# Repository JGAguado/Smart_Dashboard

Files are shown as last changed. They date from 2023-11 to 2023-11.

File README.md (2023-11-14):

[][documentation]
[][releases]
[](LICENSE)

[][maintenance]
[][buymecoffee]

# Smart Dashboard
The Smart Dashboard is a platform to help display any kind of information on two kinds of ePaper display: the 7.5" black & white display and the 7.3" 7-colors display, both from Waveshare. It includes a BMP280 sensor for air temperature and pressure as well as all the electronics to work with the minimum power consumption, supporting solar charging.

<p float="left">
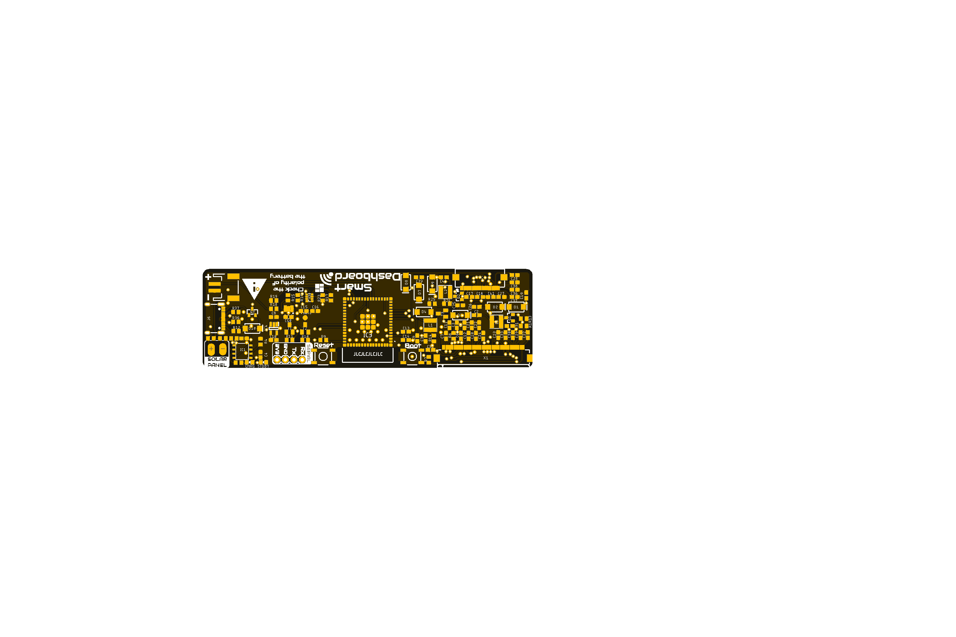
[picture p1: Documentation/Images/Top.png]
   
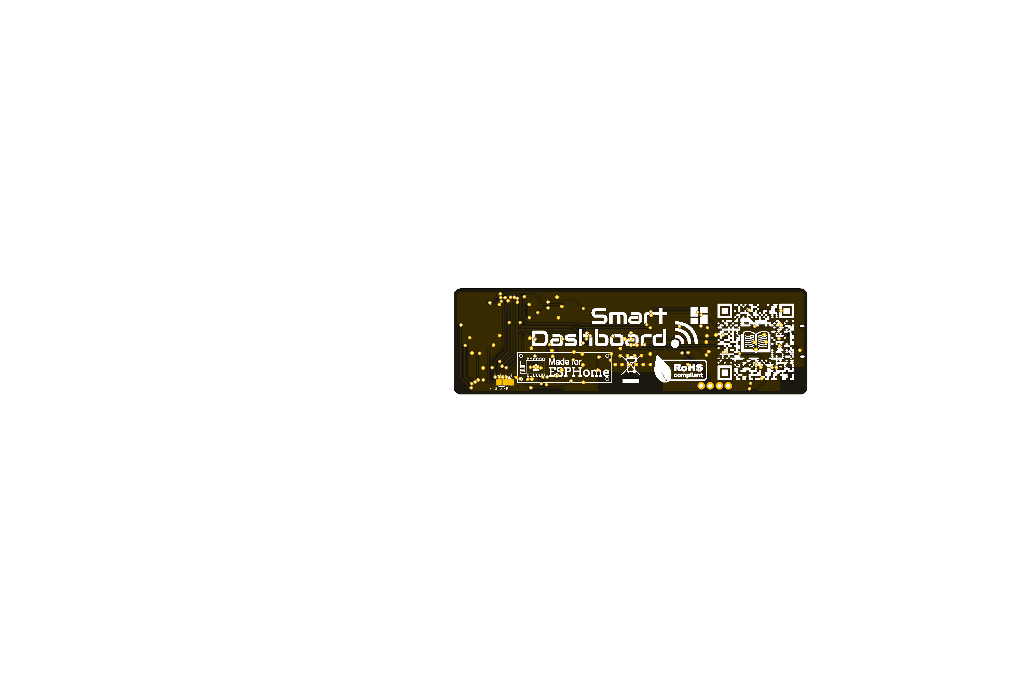
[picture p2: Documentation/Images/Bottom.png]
      
</p>

## Project tree

<li><a href="./Design/">Design</a></li>
<li><a href="./Documentation/">Documentation</a></li>

<li><a href="./README.md">README.md</a></li>

[documentation-shield]: https://readthedocs.org/projects/smart-dashboard/badge/?version=latest&style=for-the-badge
[documentation]: https://smart-dashboard.readthedocs.io

[releases-shield]: https://img.shields.io/github/release/JGAguado/Smart_Dashboard.svg?style=for-the-badge
[releases]: https://github.com/JGAguado/Smart_Dashboard/releases

[license-shield]: https://img.shields.io/badge/License-CC%20BY--NC--SA%204.0-lightgrey.svg?style=for-the-badge

[maintenance-shield]: https://img.shields.io/badge/maintainer-J.%20G.%20Aguado-blue.svg?style=for-the-badge
[maintenance]: https://github.com/JGAguado

[buymecoffee-shield]: https://img.shields.io/badge/buy%20me%20a%20coffee-support-yellow.svg?style=for-the-badge
[buymecoffee]: https://www.buymeacoffee.com/J.G.Aguado

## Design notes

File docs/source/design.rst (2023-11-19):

📐 Design
===========================

Electronic schematics
---------------------
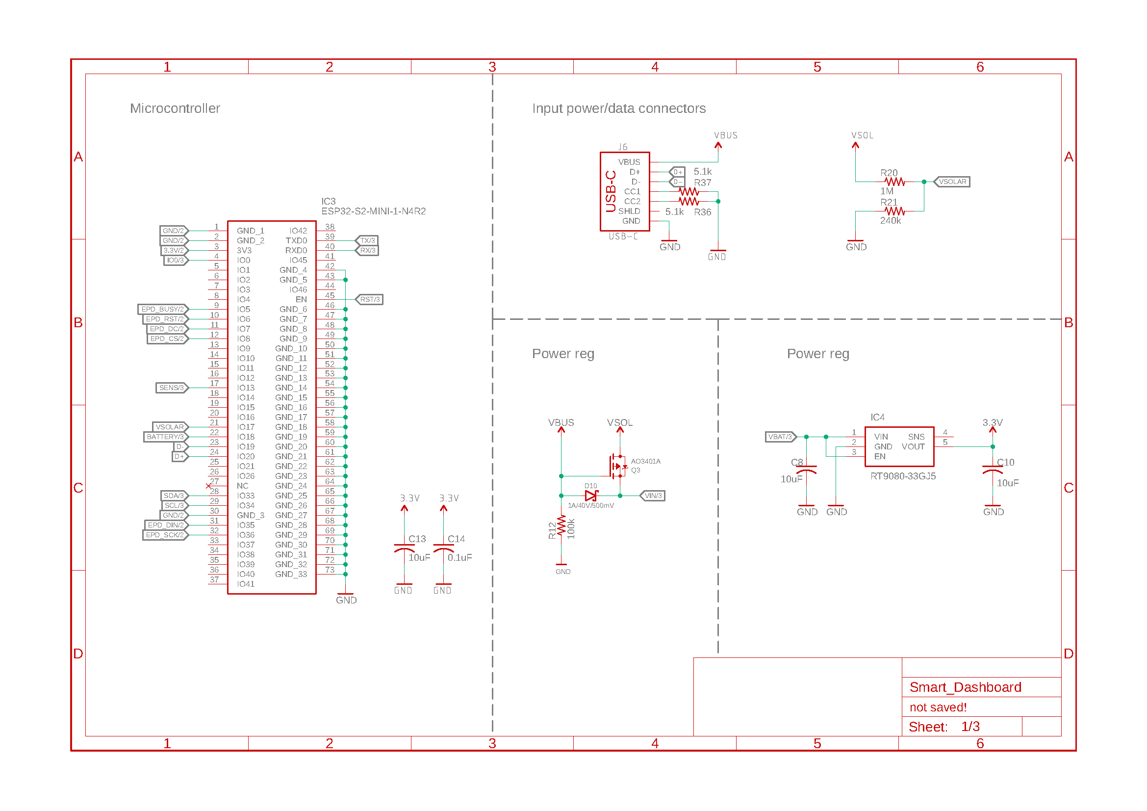
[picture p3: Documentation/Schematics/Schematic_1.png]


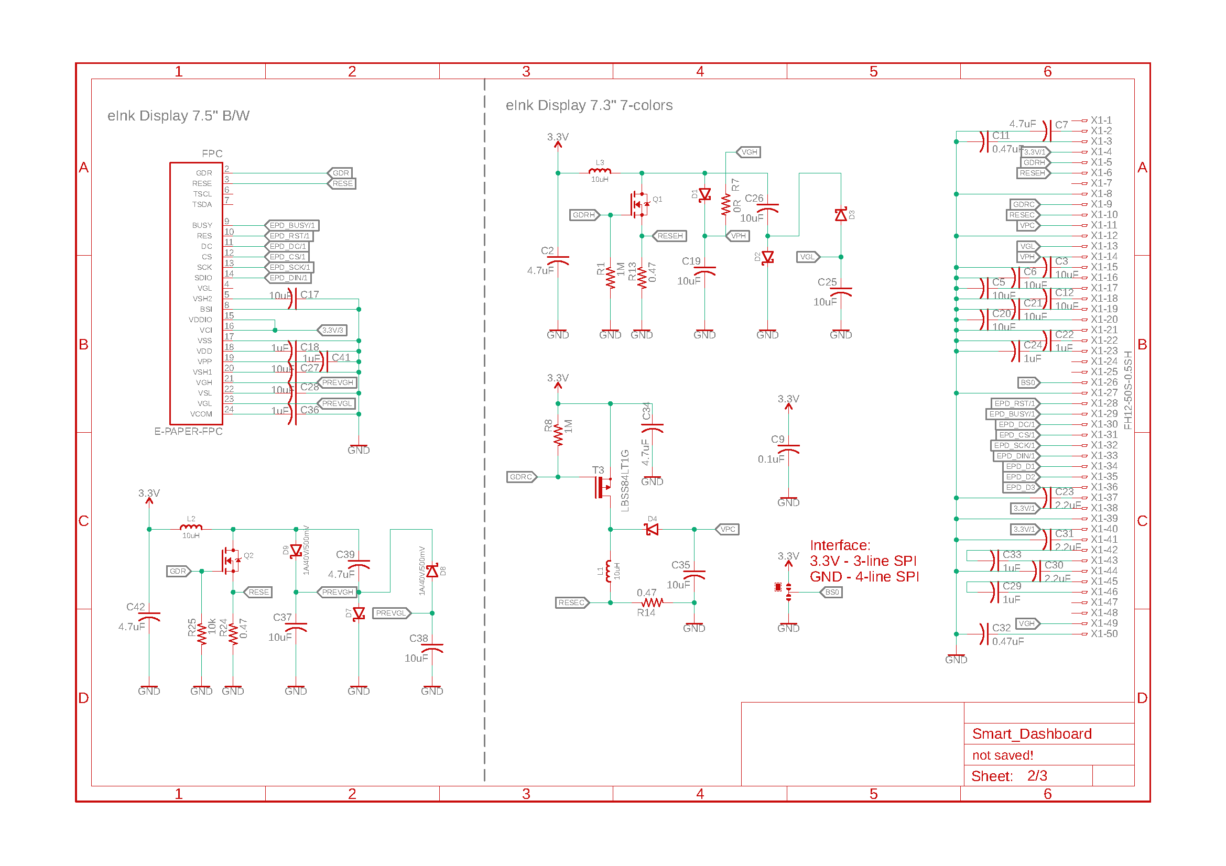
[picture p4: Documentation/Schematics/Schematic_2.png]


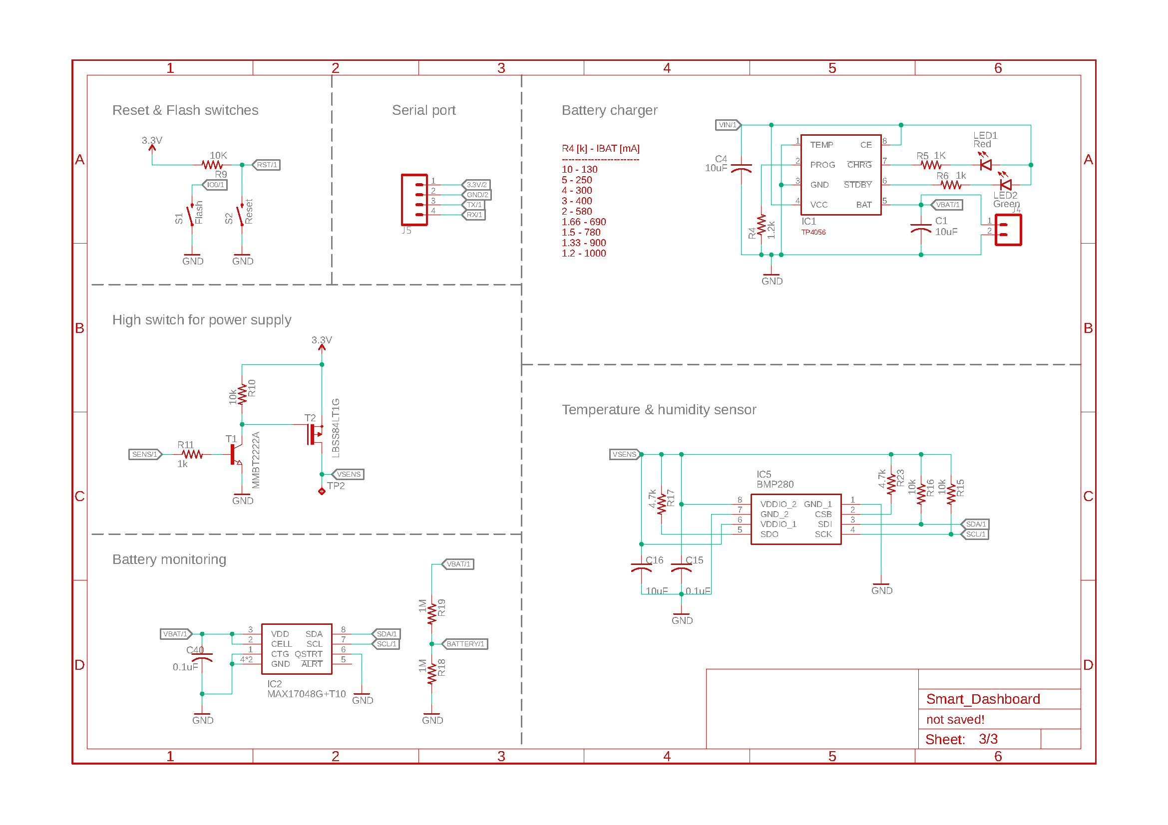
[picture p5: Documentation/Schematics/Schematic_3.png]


:download:`Download PDF <../../Documentation/Schematics/Schematic.pdf>`

.. _pcb:

:term:`PCB`
----------

.. raw:: html

    <iframe src="_static/ibom.html" height="800px" width="100%"></iframe>

.. _dock:

Dock stand
-----------------------

.. Caution::
    The following enclosure was designed for 5050100 (100x50x5mm) 4000mAh LiPo battery. The recommended battery wouldn't fit in this enclosure.

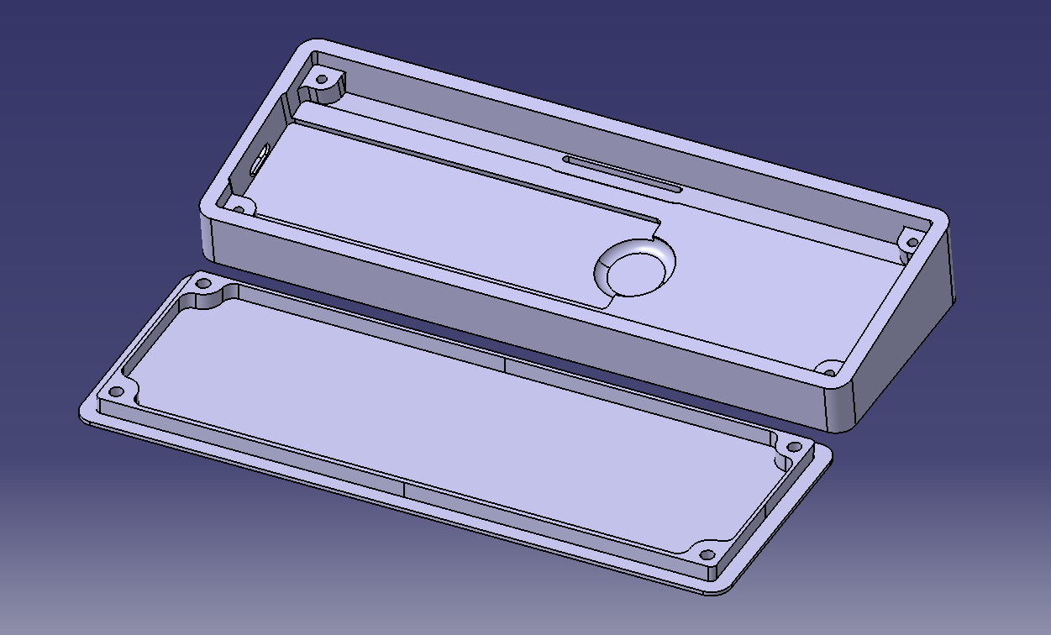
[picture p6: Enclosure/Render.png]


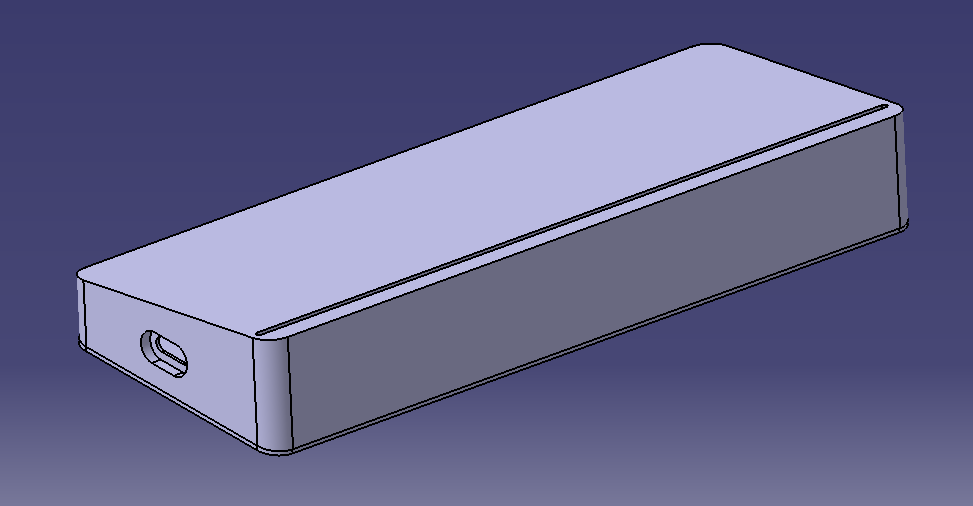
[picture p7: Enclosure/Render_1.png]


|
- :download:`Bottom <../../Enclosure/Bottom.stl>`
- :download:`Top <../../Enclosure/Top.stl>`

Technical Specifications
--------------------------

Microcontroller 
^^^^^^^^^^^^
.. list-table:: 
    :widths: 50 80
    :stub-columns: 1

    * - Module
      - ESP32-S2-MINI-1
    * - SoC
      - Xtensa® singlecore 32-bit LX7 up to 240MHz
    * - Flash
      - 4MB
    * - PSRAM
      - 2MB

Power
^^^^^^^^^^^^

.. list-table:: 
    :widths: 50 80
    :stub-columns: 1

    * - Battery 
      - LiPo 3.7 V 5000 mAh
    * - Input (USB/Solar panel)
      - 5V @ 500mA

Features
^^^^^^^^^^^^

.. list-table:: 
    :widths: 50 80
    :stub-columns: 1

    * - Interface 
      - USB Type C 
    * - 
      - 2.4GHz WiFi 
    * - 
      - UART
    * - Display
      - 7.5" B&W E-Ink display 
    * - 
      - 7.3" ACeP 7-Color E-Ink Display
    * - Sensors
      - BMP280 air temperature & pressure (digital :math:`I^2C`)
    * - 
      - MAX17048 battery voltage level sensor (digital :math:`I^2C`)

Dimensions
^^^^^^^^^^^^

.. list-table:: 
    :widths: 50 80
    :stub-columns: 1

    * - Size 
      - 100x30mm
    * - Weight
      - 15g

Environment
^^^^^^^^^^^^

.. list-table:: 
    :widths: 50 20 20 20 20 20
    :header-rows: 1
    :stub-columns: 1

    * - Parameter
      - Symbol
      - Min.
      - Typ.
      - Max.
      - Unit
    * - Working temperature [1]_
      - :math:`T_{amb}`
      - 0
      - 25 
      - 60
      - *°C*
    * - Storage temperature [1]_
      - :math:`T_{amb}`
      - 0
      - 25 
      - 60
      - *°C*

.. [1] Based on components datasheets.

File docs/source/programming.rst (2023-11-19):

💻 Programming
===============

There are two main programming methods supported and tested with the |Product|: 
 * ESPHome
 * Arduino

In both scenarios, you will first need to enter the board into flashing mode. For that, press and hold the *Flash* pushbutton
while you reset the board (pressing once the *Reset* pushbutton).

.. Note::
    For flashing new firmwares, if the :term:`OTA` support is not available, you can use the USB-C or the serial port (3.3, GND, Tx, Rx).

.. Caution::
    If you decide to flash the board through the serial port, make sure to unplug the battery before (the 3.3V supply is shared).

.. _esphome:
ESPHome
---------
`ESPHome <https://esphome.io>`_ is a well known platform for programming ESP-based devices 
with a very little effort. It is configured via YAML files and supports a wide range of functionalities
and sensors.

.. Note::
    At the moment, ESPHome only supports single-color E-Ink displays, so the 7-color display can **not** be used with ESPHome.

.. Important::
    For using ESPHome, and all its funcionalities, you need to have a `Home Assistant <https://www.home-assistant.io>`_ (HA) instance running
    in the same network as your |Product|.

.. Tip::
    A very easy way to upload and copy files (code or even images) into your ESPHome folder hosted in your HA instance is 
    with the help of the Visual Studio Code integration for HA. This way you can just drag and drop the files over the folder 
    on the Home Assistant’s Visual Studio Code navigation panel on your left.

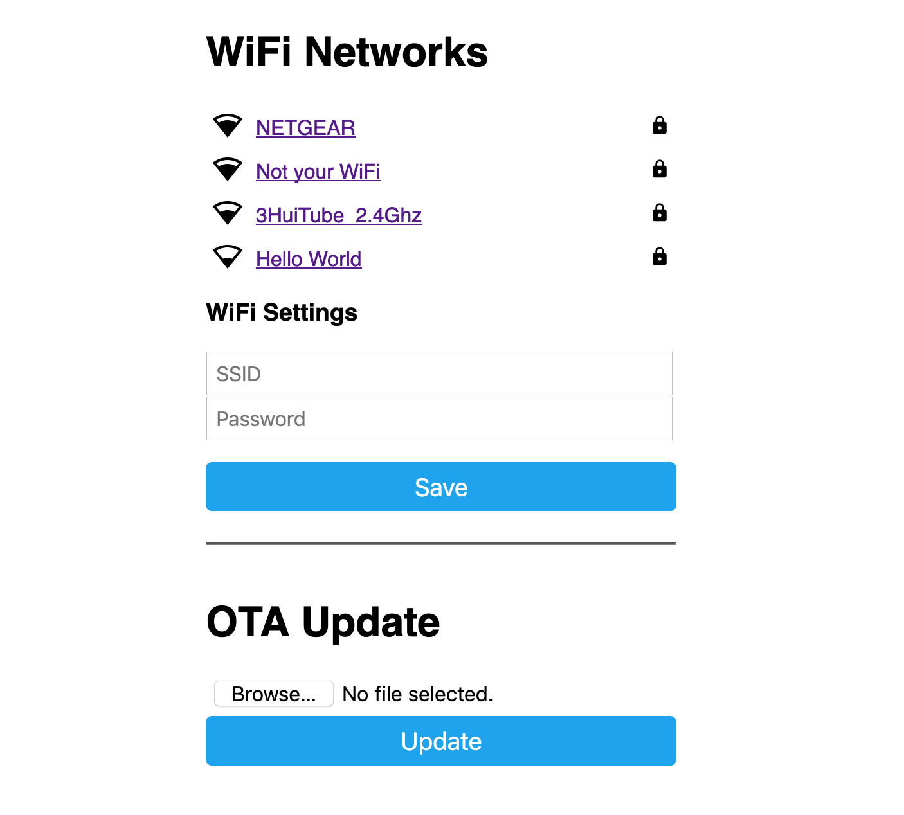
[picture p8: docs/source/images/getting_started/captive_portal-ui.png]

    
The |Product| already comes with an embeded version of ESPHome, that would only require an :term:`OTA` update
to get it ready to work in your network:

1. Power the board, and let it run for 1-2 minutes. When the board cannot connect to a WiFi network, it will 
   create a fallback hotspot.
2. Use a smartphone or tablet and go to the WiFi settings, connect to the recently created *Smart-Plant* hotspot with the password *smartplant*.
3. Access to the captive portal and open the browser if doesn't pop up automatically.
4. Enter your network setttings and press *Save*.

Now, your ESPHome device is ready to be found by Home Assistant in your network. Add it from the ESPHome section to add 
and edit a customized configuration file.

As an example of such configuration setup (and the one flashed on the factory settings of the |Product|) 
with all the dependencies:

| esphome
| ├── images
| │   └── Screenshot bw.png
| ├── libraries
| │   └── MAX17048.h
| └── smart-dashboard.yaml
| 
| 

In the folder structure above:

``Screenshot bw.png``
    This is the background image to serve as an example of any background image you can add to your Smart Dashboard.

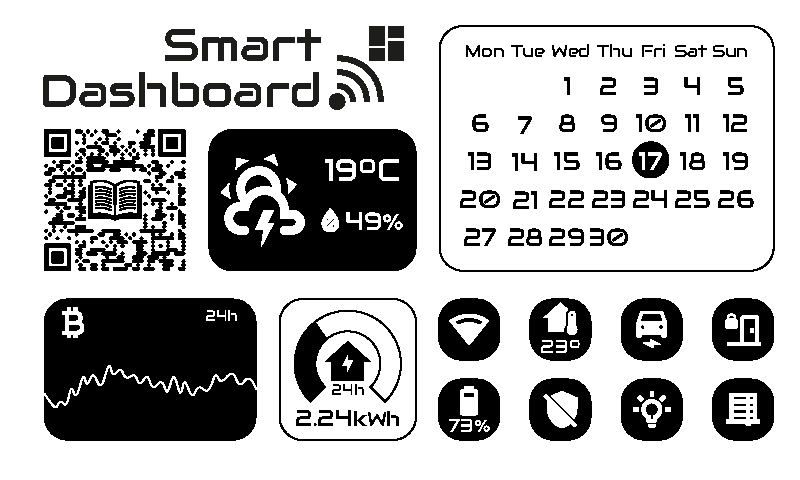
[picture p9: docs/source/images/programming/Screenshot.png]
    

``MAX17048``
    This is the library to read the MAX17048 sensor (battery level):

    .. literalinclude:: files/MAX17048.h
        :language: C
        :linenos:

``smart-dashboard.yaml``
    This is the YAML configuration file, the most important file that configures your ESPHome-based Smart Dashboard:

    .. literalinclude:: files/configuration.yaml
        :language: yaml
        :linenos:

Arduino
--------
If you are still interested in programming directly with the Arduino IDE, the procedure is no 
different than with any other ESP32 devices:

1. Open the Arduino IDE and go to File -> Preferences option.
2. Add to the *Additional Boards Manager URSLs* the url:

.. parsed-literal::

    https://raw.githubusercontent.com/espressif/arduino-esp32/gh-pages/package_esp32_index.json

3. Close the preferences and open in the menu Tools -> Board -> Boards Manager.
4. Search for *esp32* and install it. This might take some time.
5. Now you can select the board *ESP32 Dev Module* as the target board. Leave the rest of parameters 
   by default.
6. The right libraries from the e-paper displays can be found directly at Waveshare's documentation website:

- `800×480, 7.5" E-Ink display <https://www.waveshare.com/wiki/7.5inch_e-Paper_HAT_Manual#Working_With_Arduino>`_.
- `800×480, 7.3" ACeP 7-Color E-Ink Display <https://www.waveshare.com/wiki/7.3inch_e-Paper_HAT_(F)_Manual#Working_With_Arduino>`_.

7. Select the correct port and remember to enter the board into flashing mode before uploading the sketch.

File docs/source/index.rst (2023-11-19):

Smart Dashboard
###############

.. raw:: html
        
    <iframe src="_static/carousel.html" style="width: 100%; height: 300px; border: none;"></iframe>

Welcome to the documentation page of the |Product|, a device to show all the data that want on a big e-paper display.

With the |Product| you can chose to drive Waveshare's 7.5" e-ink display in black and white or the 7.3" 7-colors e-paper model.

Since it is thought to run on your desk, displaying all the important information that matters to you, it can run in low-consumption modes (unless externally powered),
entering into deep-sleeps in between displays updates. Therefore, it integrates high-efficient :term:`LDO` in standby modes and even support for an external solar cell. 

Everything packed in a quite compact board that can be mounted in a conventional photo frame, or any dock stand of your design.

Contents
--------

:doc:`safety`
    How to operate and manipulate the |Product|.

:doc:`getting_started`
    First steps for configuring and working with the |Product|.

:doc:`programming`
    Example firmware files for the |Product|.

:doc:`design`
    Design files of the |Product|.

.. _support:

Technical support
-----------------

If you have technical problems or cannot find the information that you need in the provided documentation, 
please contact me directly:

:Author: |Author|
:Contact: |Email|

:Board: |Product|
:Version: |Version|
:Date: |Date|

.. toctree::
   :maxdepth: 2
   :hidden:

   safety   
   getting_started
   programming
   design   
   glossary
   faq

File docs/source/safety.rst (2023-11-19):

🦺 Safety guidelines
=================

These safety guidelines, the operation instructions and the limit values listed in :doc:`specs` are to be read carefully before operating the product.

.. Caution::
    This product has been designed for being used in domotic applications. 
    It was not designed for any use involving serious risks or hazards that could lead to death, injury, serious physical damage, or loss of any kind without the implementation of exceptionally stringent safety precautions.

:term:`LiPo` battery powered
----------------------
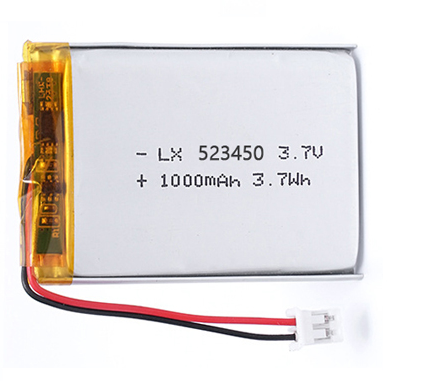
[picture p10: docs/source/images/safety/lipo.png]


Due to the high power density of :term:`LiPo` batteries, the |Product| is powered directly by a 5000mAh :term:`LiPo` battery. Therefore there are specific electronics embeded in charge of the battery 
management, including charge/discharge of the battery and protections against low-voltage levels and short-circuits. 

However it's not recommended to leave the product unatended while charging for long time through the C-Type USB. In case you observe a high increase of the device's temperature or you 
smell burn, immediatelly disconnect the device from the charging USB.

In case you are using the optional solar panel for extending the autonomy and you feel the device gets too hot from the solar charging, please cover the solar panel until you see 
the charging LED goes off.

If you have any question, please check with technical support (:ref:`support`) before taking any action potentially dangerous.

Protection against :term:`ESD`
------------------------------

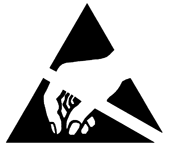
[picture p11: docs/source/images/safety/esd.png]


The |Product| contains components sensitive to :term:`ESD`, which can be damaged by inappropriate handling. 
It's therefore necessary to provide some safety precautions against :term:`ESD` during the handling and operation.

Usage, transport and storage
----------------------------

During the use, transport and storage, this product must be protected from any mechanical stress 
(forces applied over the board or it's components), temperatures out of the data-sheet's range, high 
environmental humidity or aggressive atmospheres.

Avoid using it in areas where it cannot be assured the previously mentioned environmental conditions.

Repairs
-------

If any of the components on the board gets damaged, a reparation is possible. This repair can be performed by 
yourself if you identify the problem and have the means for desoldering & soldering. If this is not the case,
just write to the :ref:`support` mail to reach a solution.

Disposal
--------

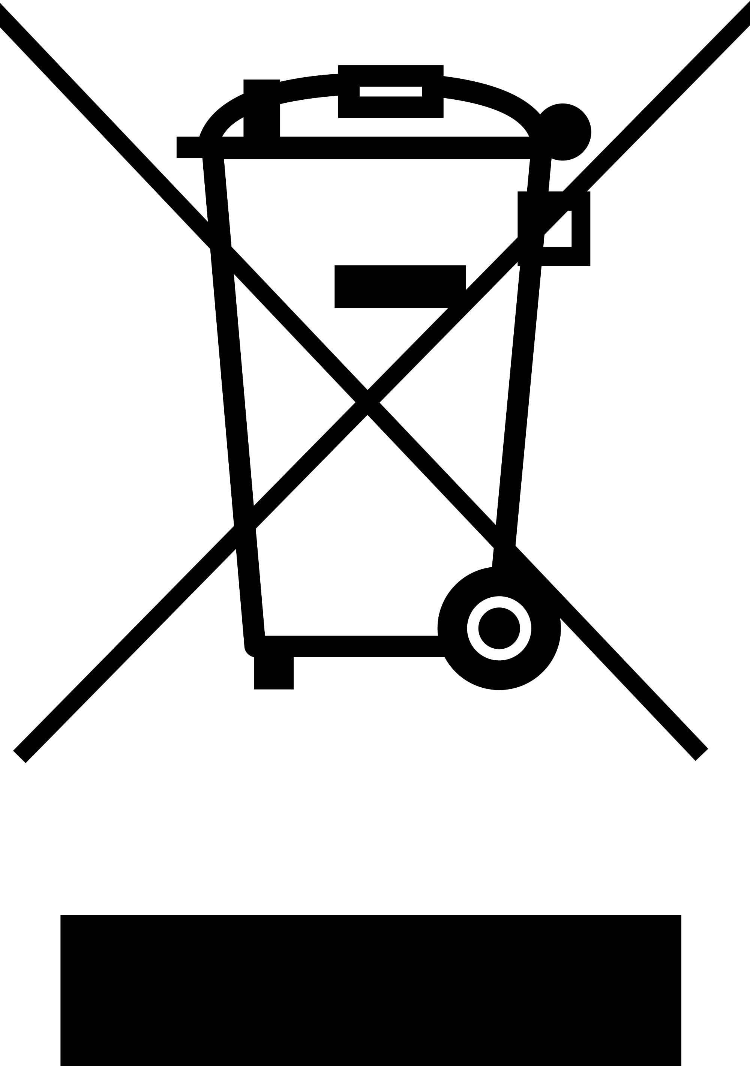
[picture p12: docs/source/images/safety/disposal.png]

    
In accordance with national and local environmental protection and material recovery and recycling regulations, 
electronic devices that can no longer be used (in case a repair is not possible) must be disposed of separately 
and not with normal household garbage.

Restriction of Hazardous Substances
-----------------------------------

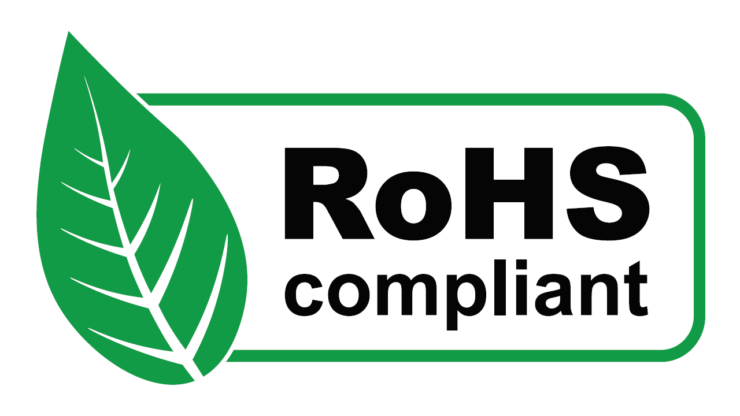
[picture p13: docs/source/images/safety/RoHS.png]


The :term:`PCB` and the electronic components mounted on the |Product| have been manufactured attending to the EU rules 
restricting the use of hazardous substances (RoHS) in electrical and electronic equipment to protect the 
environment and public health.

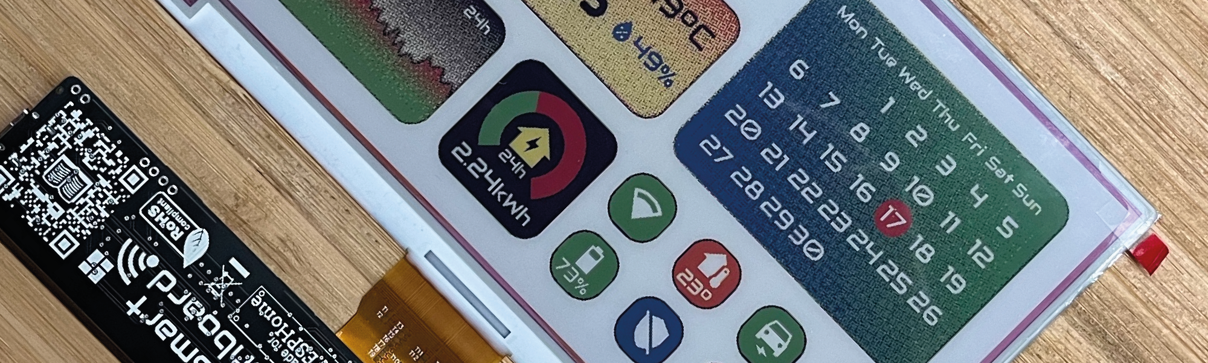
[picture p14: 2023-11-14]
docs/source/_static/Slide 2.png

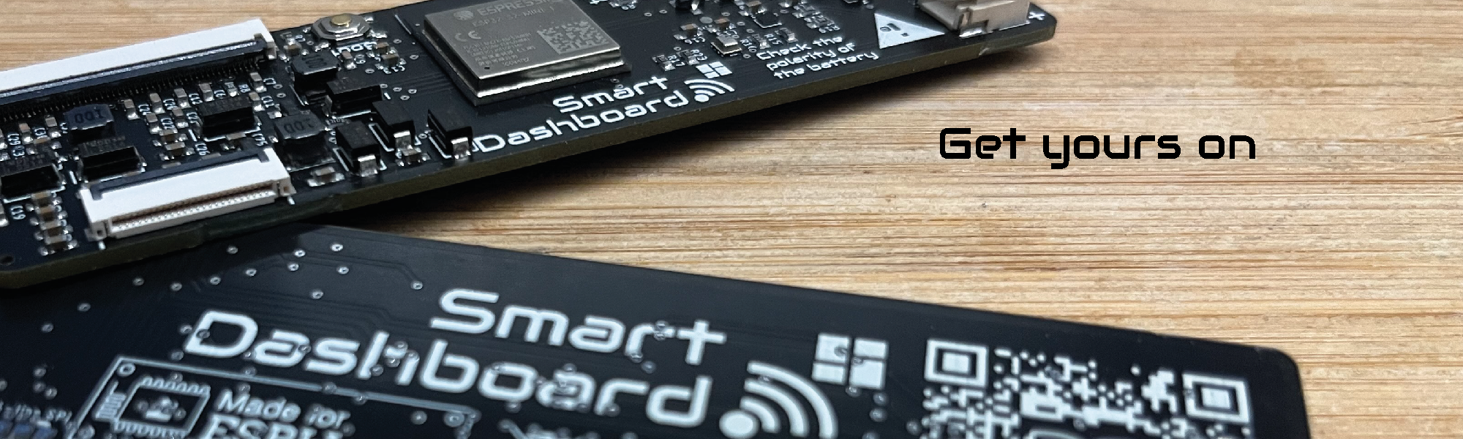
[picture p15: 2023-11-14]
docs/source/_static/Slide 3.png

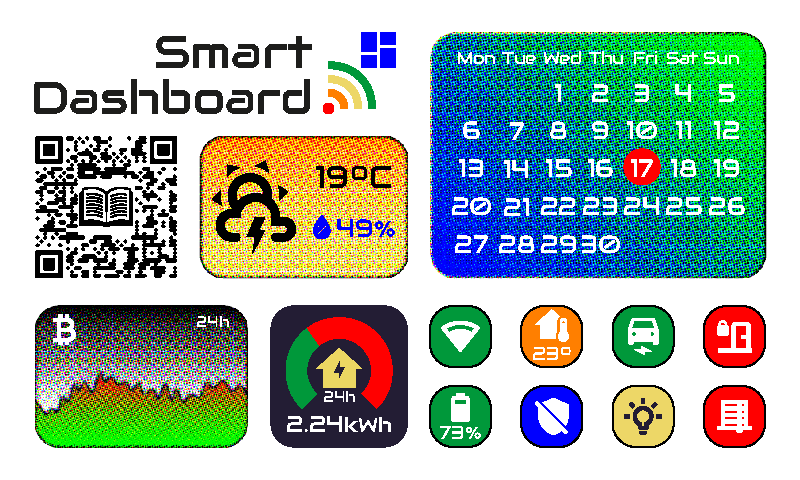
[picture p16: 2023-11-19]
docs/source/images/programming/Screenshot_color.png

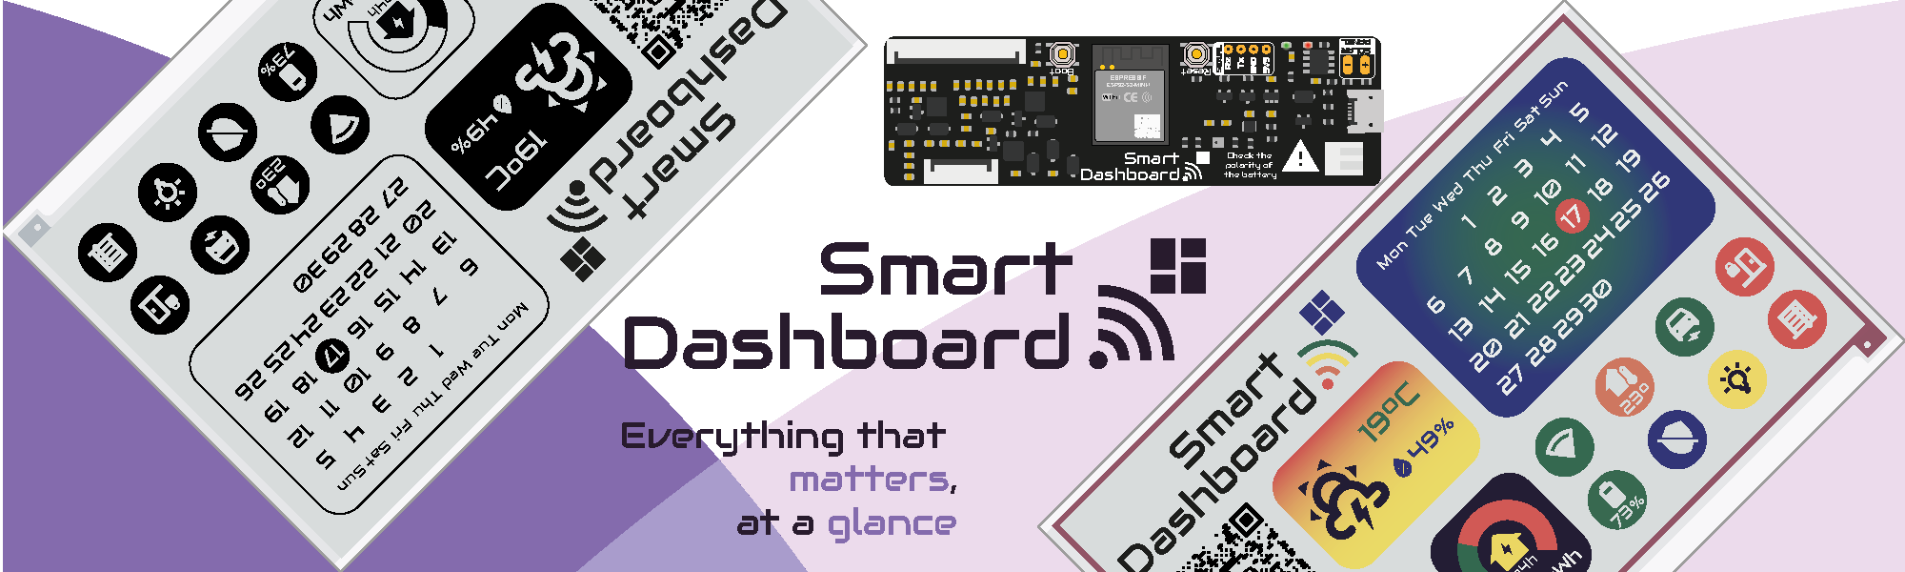
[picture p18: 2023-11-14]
docs/source/_static/Slide 1.png

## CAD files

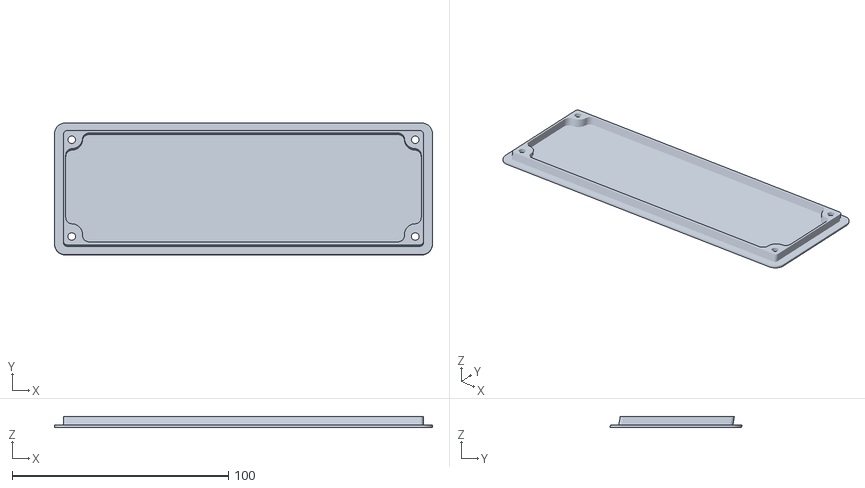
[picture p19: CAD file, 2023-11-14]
Enclosure/Bottom.stl
175.0 x 61.1 x 4.92

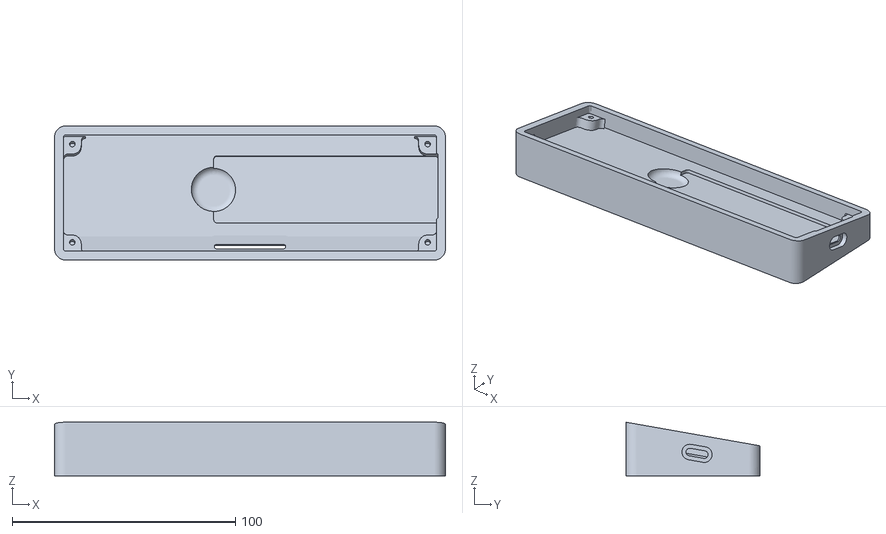
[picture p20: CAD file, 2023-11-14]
Enclosure/Top.stl
175.0 x 60.0 x 24.0

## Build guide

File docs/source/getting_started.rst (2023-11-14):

💡 Getting started
===============

Assembly 
----------
Due to the high amount of components integrated in such small PCB layout, most of them are too small to be soldered at home by you. Therefore, these boards come already 
with the components assembled. 

The |Product|, in addition to the PCB assembled board, consist on the following parts:

- An e-paper display. The recommended (and tested working) e-ink panels are the `800×480, 7.5" E-Ink display <https://www.waveshare.com/7.5inch-e-Paper.htm>`_ or the  
  `800×480, 7.3" ACeP 7-Color E-Ink Display <https://www.waveshare.com/7.3inch-e-Paper-F.htm>`_. Please note only one display can be connected at the same time and 
  that **other displays may not work at all**.
- A :term:`LiPo` battery, with a recommended 5000mAh capacity, for space and power. The 6060100 3.7V 5000mAh LiPo battery meets this criteria.
- An :ref:`dock` for allocating the electronics + battery + e-paper display. 
- Optionally, you can mount a solar panel that charges the battery under the right sunny conditions. The output voltage of the panel musn't excess the 6V.

Powering
--------
The |Product| is be powered through a :term:`LiPo` battery plugged into the white JST connector. The voltage of the battery is regulated to the working 3.3V through a low-consumption :term:`LDO`.

.. Caution::
    Connect the battery after clamping the e-paper connector and be careful when plugging it or removing it, since the connector can be hard to plug/unplug.

In order to charge the battery, there is a battery management IC that provides the right charging curve to the :term:`LiPo` battery and offers a visual indicator (red LED for charging, 
green LED for standby) while the battery is being charged. There are two ways of charging the |Product|: USB-C or solar panel.

Solar panel
^^^^^^^^^^^^^

    
In addition to the USB-C, and with the aim of extending the service time between (USB) charges of the battery, the |Product| can be configured to be powered from a solar panel. This feature 
would imply soldering the solar pannel to the board as indicated in the figure.

USB-C
^^^^^^^^^^^^^
The USB Type-C is a very extended port for portable electronics, and because of it's standarized 5V power supply is ideal for charging the |Product|.

Sensors
--------
    
As the |Product| is intended to work during long periods of time without having to be recharged, it is important to avoid undesired consumptions 
durint the deep-sleep periods. This implies that the sensors have to be powered **only** when they are needed. 

Therefore there is a high-switch circuit that enables/disables the powering of the *sensors power line* connected to the microcontroller's output **GPIO4**.

Regarding the embedded sensors they use the digital bus :term:`IIC` (:math:`I^2C`), which are physically defined with the following pinout:

:SDA: **GPIO33**
:SCL: **GPIO34**

Ambient temperature & pressure 
^^^^^^^^^^^^^^^^^^^^^^^^^^^^^^^
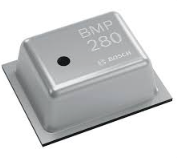
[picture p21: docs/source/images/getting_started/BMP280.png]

The |Product| embeds an BMP280 temperature and pressure sensor ready to deliver calibrated data through the :math:`I^2C` bus.

This sensor has an operational pressure range of 300 up to 1100 hPa ( with a ±1hPa typical accuracy), and a temperature range of -40 to 85 °C (±1 °C typical accuracy)

The :math:`I^2C` address is **0x77**.

Battery level
^^^^^^^^^^^^^^^^
For measuring the battery level, the |Product| integrates the MAX17048 :term:`IC`.

This sensor measures the voltage of the LiPo cell and does the math to get an estimative percentage of the battery level.

The :math:`I^2C` address is **0x36**.

E-paper
--------

The |Product| is capable of driving two different e-paper displays: 

- `800×480, 7.5" E-Ink display <https://www.waveshare.com/7.5inch-e-Paper.htm>`_.
- `800×480, 7.3" ACeP 7-Color E-Ink Display <https://www.waveshare.com/7.3inch-e-Paper-F.htm>`_.

However only one can be driven at the same time, since they share the SPI bus pins:

.. list-table:: Pinout table
    :widths: 10 10 
    :header-rows: 1

    * - ESP32
      - E-paper
    * - 5
      - BUSY
    * - 6
      - RST
    * - 7
      - DC/MISO
    * - 36
      - CLK
    * - 35
      - DIN/MOSI
    * - 8
      - CS

Dock stand
------------
The |Product| PCB can be mounted in a custom :ref:`dock` that you can print on your own 3D printer.

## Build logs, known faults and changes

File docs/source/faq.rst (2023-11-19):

💬 :term:`FAQ`
=============================

After connecting the battery, I don't see the e-paper refresh or any LED on.
    The two LEDs that are on the board (STDBY & CHRG) only indicate the state of the battery while charging (USB-C or solar panel). The way to 
    check if the board is alive is pressing the Reset pushbutton and see that the e-paper refreshes correctly. If not, you will need to 
    charge the battery through the USB-C. 

After connecting the battery and the USB power I see the both LED (STDBY & CHRG) on.
    Check the battery connection polarity: red with + and black/blue with -. 
    Since there is no standard relative to the JST connectors polarity, please pay 
    special attention when connecting any battery to the board. 

Can I upload ESPHome directly from the Home Assistance setup running on my Raspberry Pi?
    Yes you can, and actually this is one of the simplest and more effective way to upload ESPHome.

Can I upload firmware through the USB-C?
    Yes, the ESP32-S2 includes a full-speed USB On-The-Go (OTG) interface to enable USB communication.

When I try to compile the given YAML and upload it into the board I get some error messages saying that I miss some files (Audiowide.ttf, icon-map.h, etc). How to fix it?
    Just the configuration YAML file isn’t enough and you might get an error asking for missing items (the fonts and the images). The reason is because
    on the configuration we are asking for some files (the fonts that you want for the digits or the icons and the background image with the plant and the gauges).
    
    Therefore you need to upload into the folder with the configuration YAML file the required files. I strongly suggest to use Visual studio code and just drag and 
    drop the items according to the structure mentioned on the :ref:`esphome` programming section.

Can I use it if there is no internet connection? 
    Technically yes, the ESP32 can work without internet, but since the main strength of this board is to present data, you will still need internet to gather 
    certain data (weather forecast, stock prices, etc.). However, if you use Home Assistant it is possible that the data you want to present comes from local 
    sensors you have, in this case internet may not be that required.

Can the Smart Dashboard be used outdoor? 
    No, it wasn't designed for such case scenario. In addition, take into account that e-paper displays degrades under direct UV light exposure. 

What is battery life on single charge?
    With the ESPHome configuration YAML, (10s working and e-paper update, and 1h on deep sleep mode) the expected battery life is around 40-50 days for 
    the recommended 5000mAh LiPo. 

Can I attach a solar panel to extend the battery?
    Yes, there are two unsoldered pins marked as +/- where you can attach a 5V solar pannel of your choice. 
    Just make sure the sun exposed area is the solar panel and not the e-ink display.

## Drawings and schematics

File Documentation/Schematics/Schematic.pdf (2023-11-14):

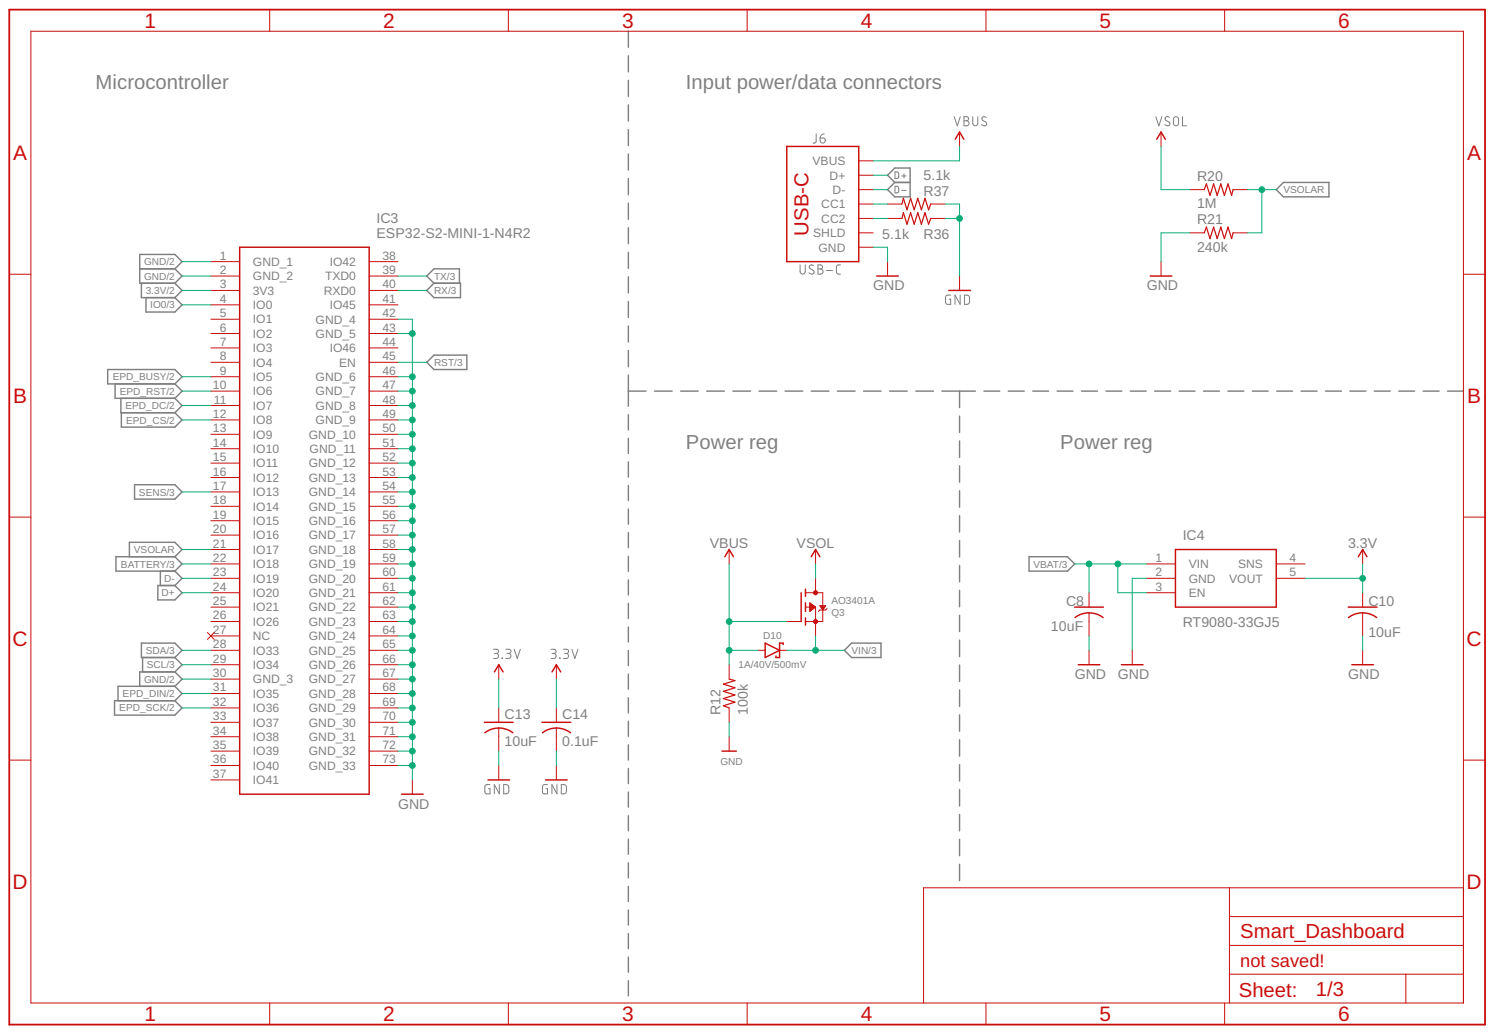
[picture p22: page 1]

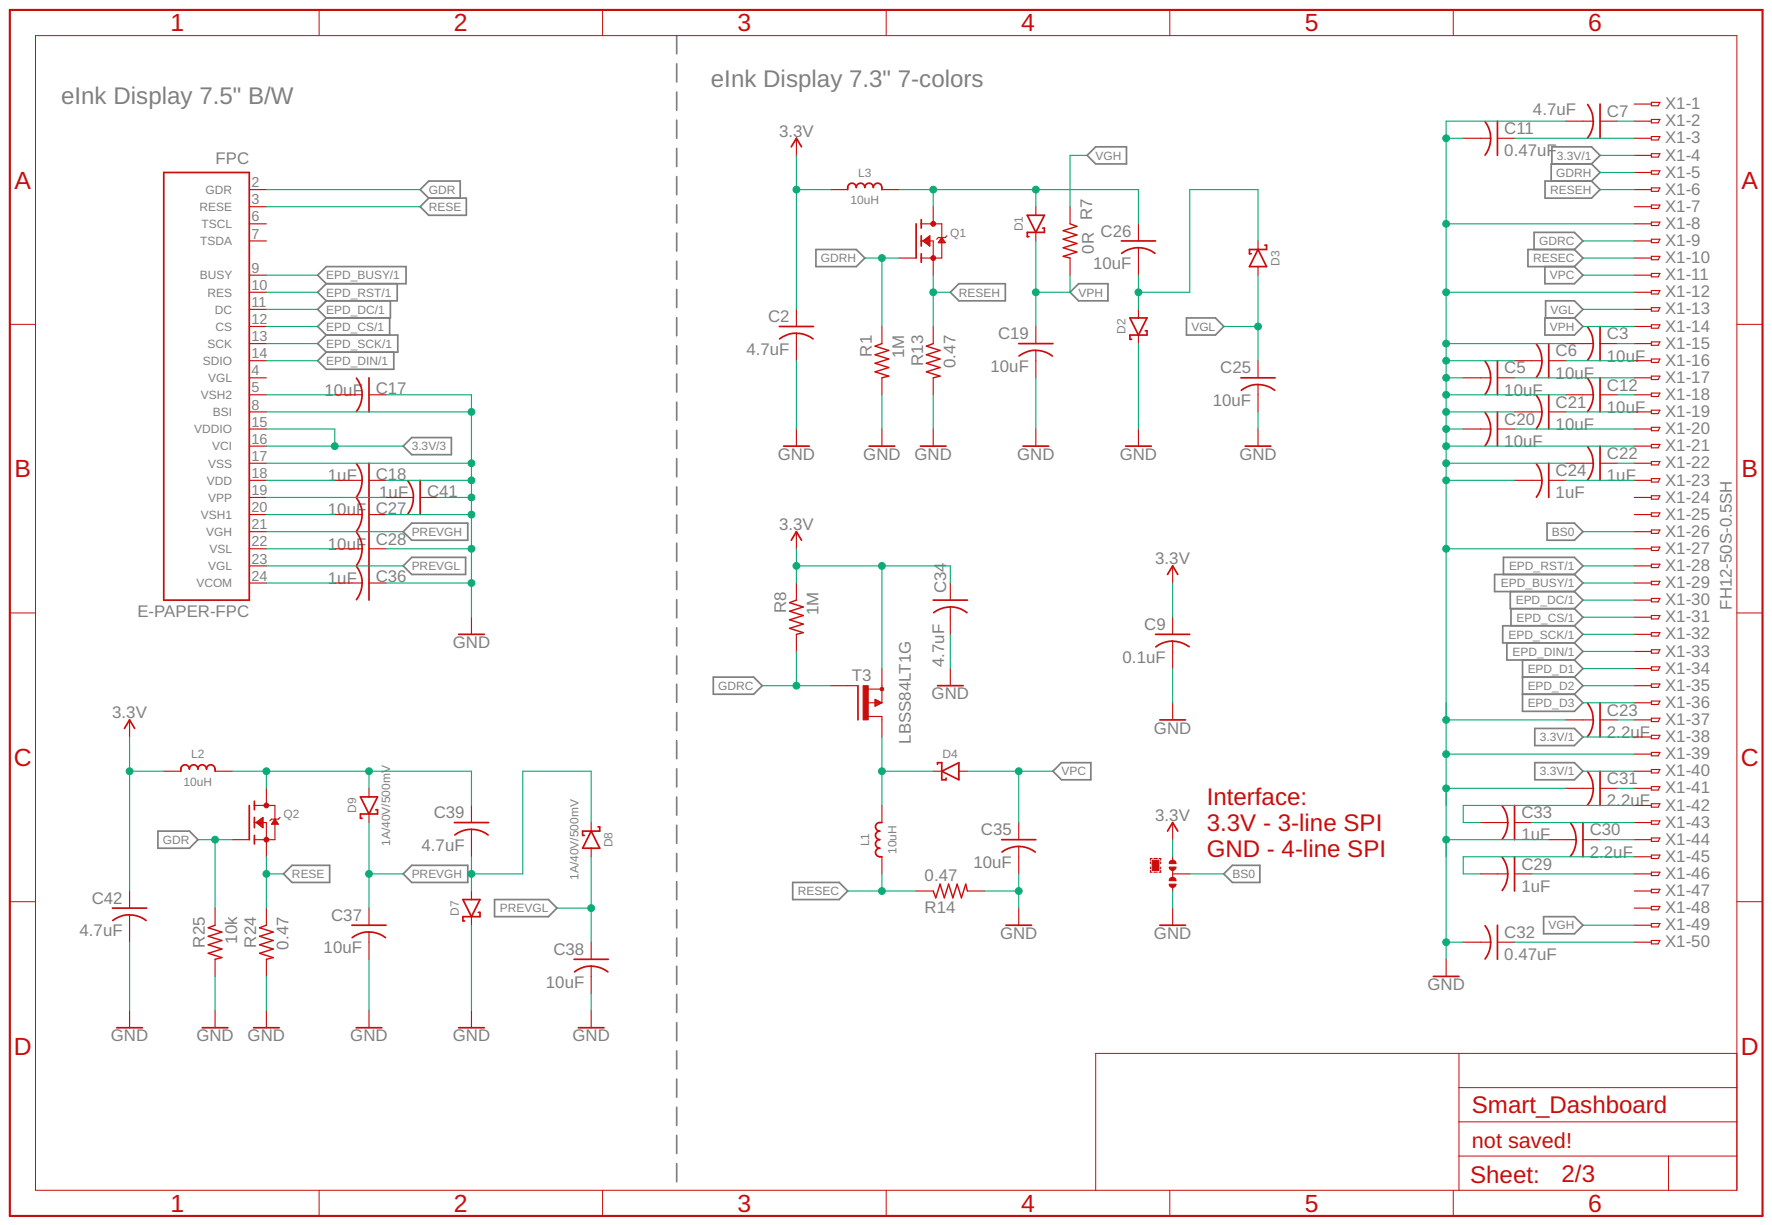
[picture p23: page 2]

0.47 GND GND GND GND

18 1uF | C18
19 | 1uF | C41
20 10uF | C27

VSL VGL VCOM E-PAPER-FPC

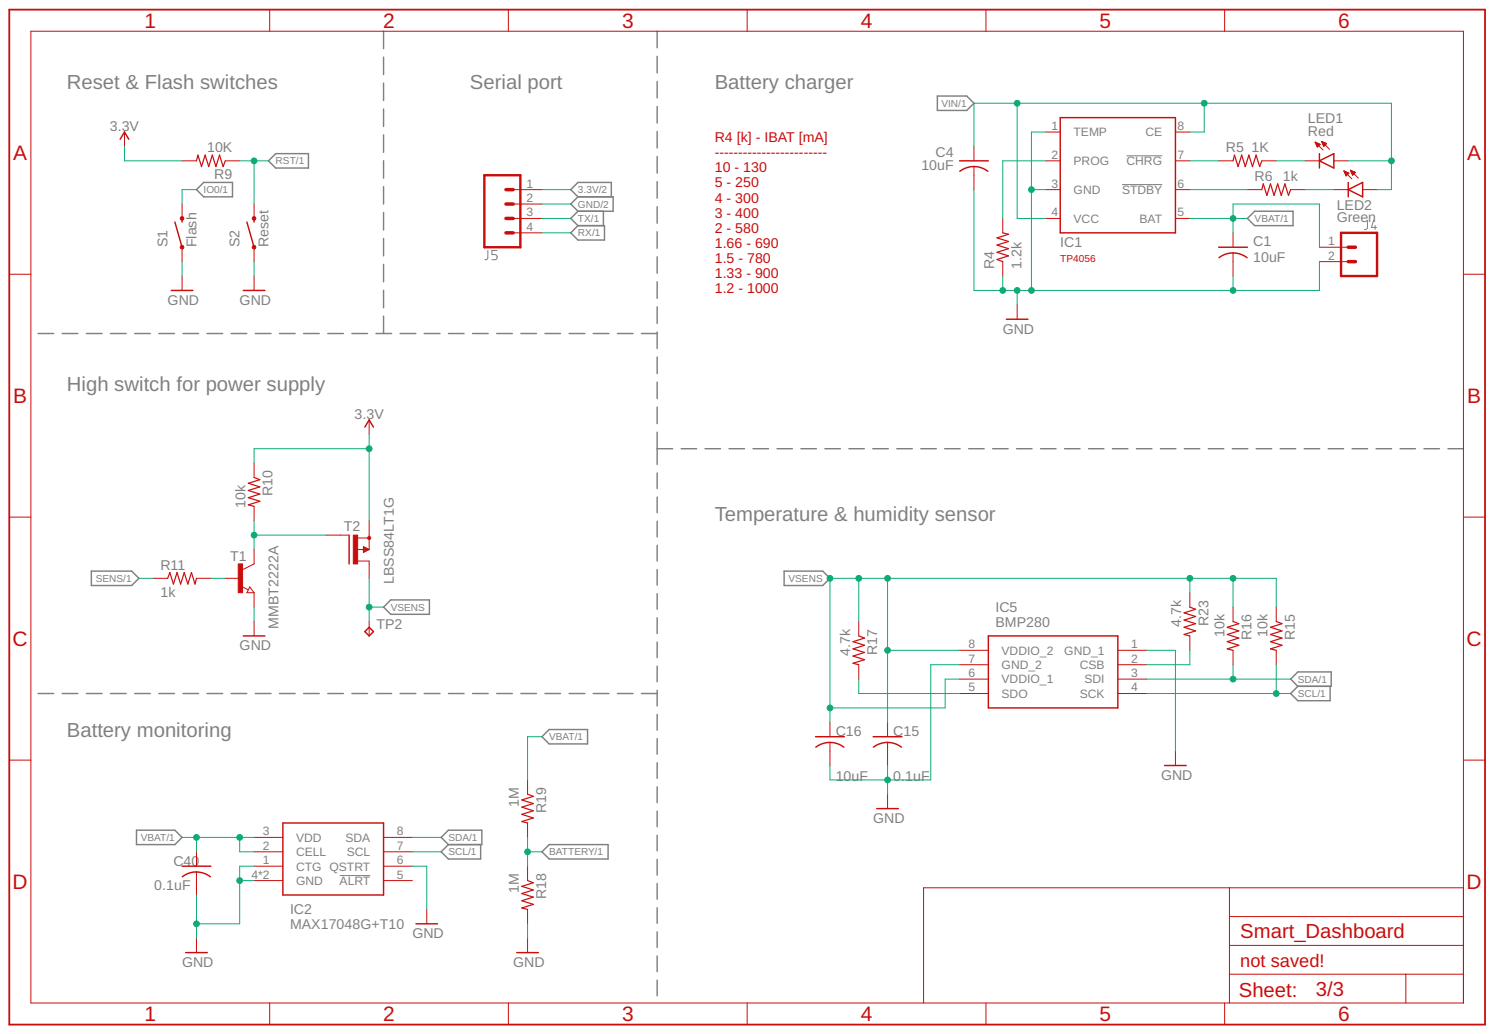
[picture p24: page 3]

High switch for power supply

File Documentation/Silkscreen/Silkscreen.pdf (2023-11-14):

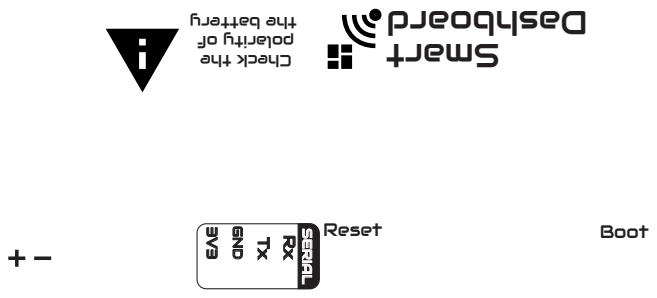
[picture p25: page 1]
Reset; Boot; GND; SERIAL

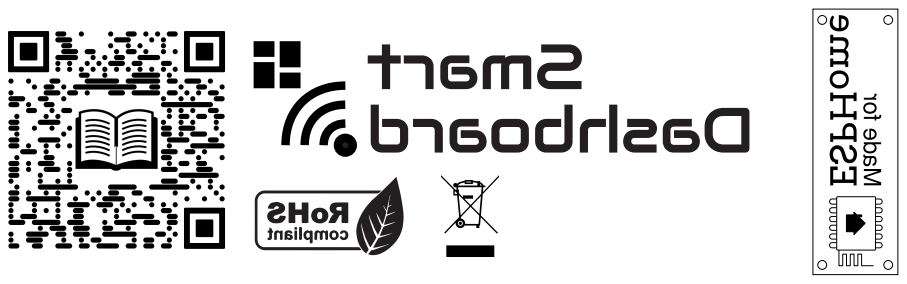
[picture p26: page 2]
Smart Dashboard

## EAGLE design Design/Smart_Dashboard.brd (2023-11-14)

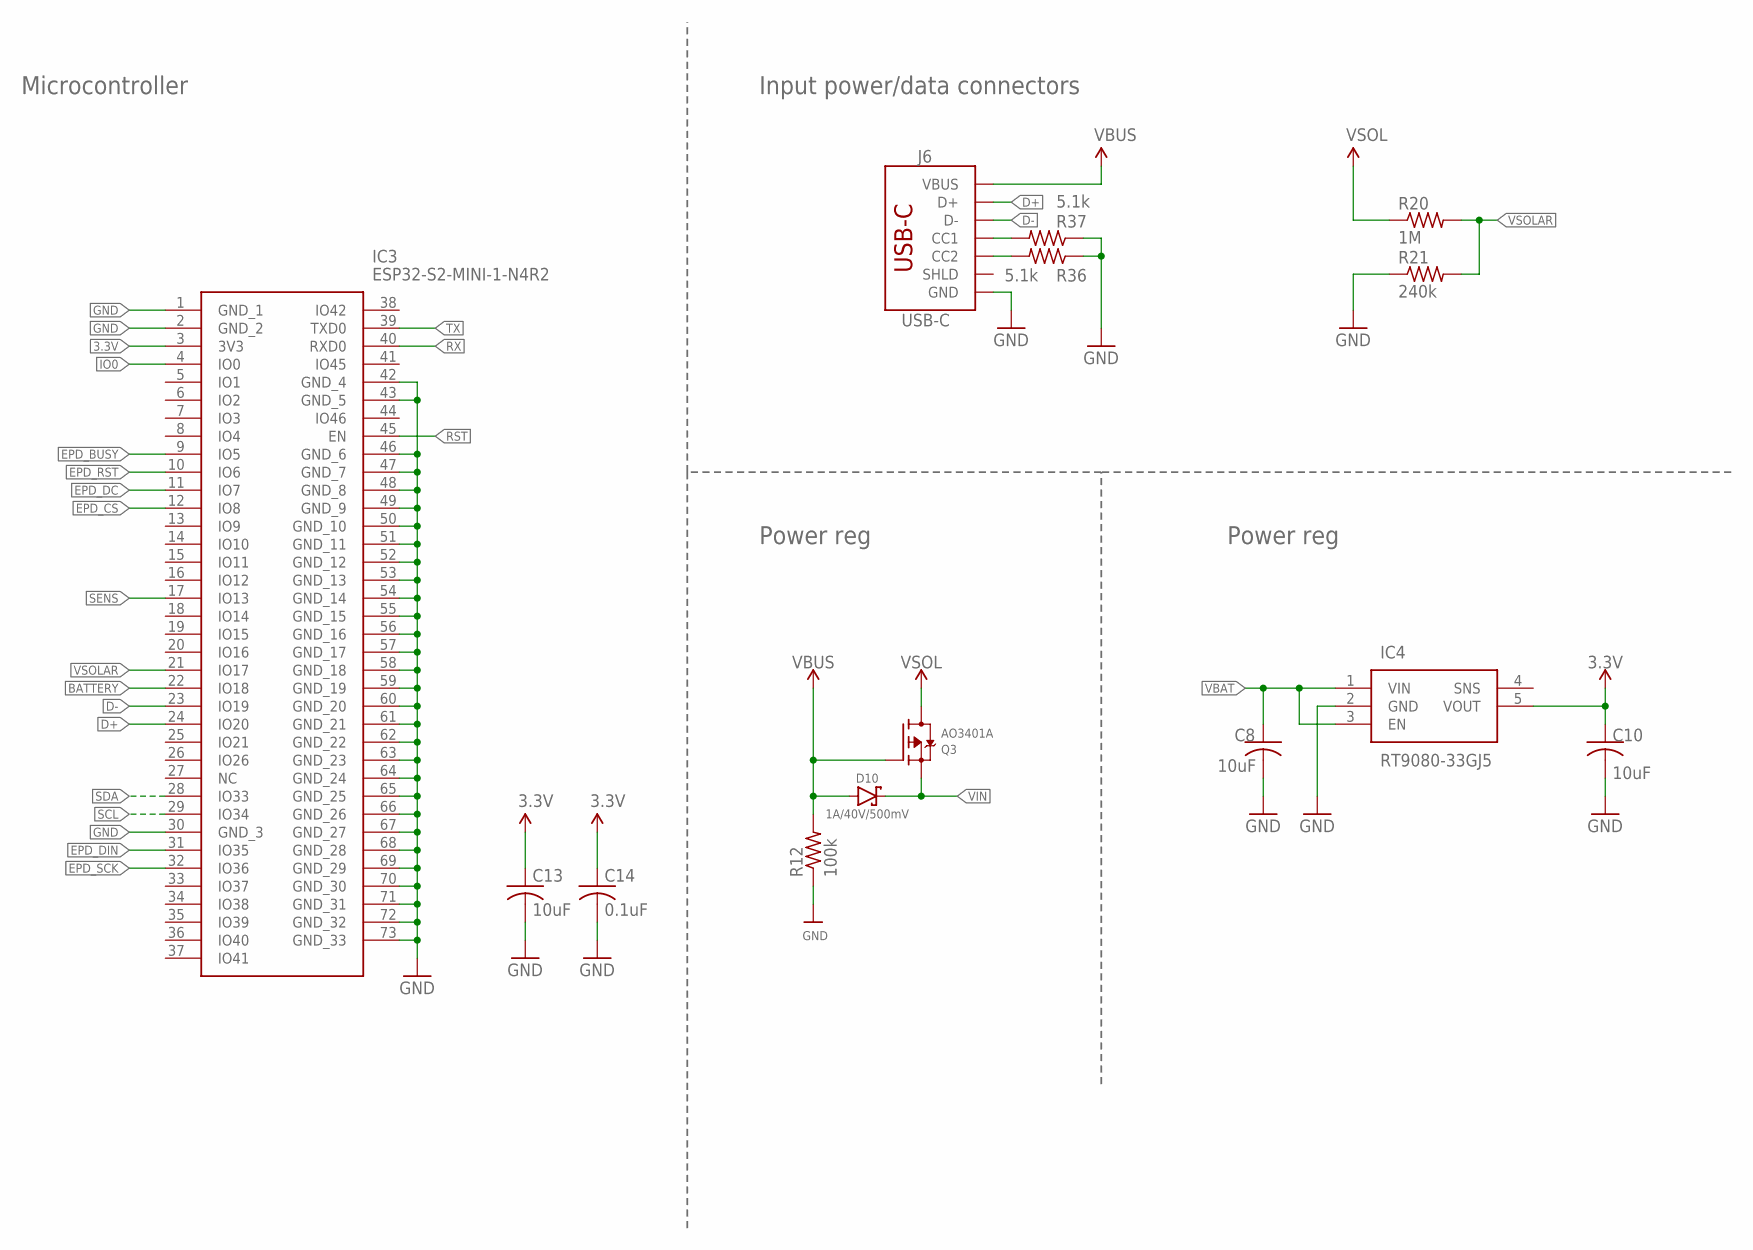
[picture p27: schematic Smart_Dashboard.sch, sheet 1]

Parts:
C8, C10, C13: 10uF; C0603
C14: 0.1uF; C0603
D10: 1A/40V/500mV; SMA-DIODE
IC3: ESP32-S2-MINI-1-N4R2; ESP32S2MINI1N4R2
IC4: RT9080-33GJ5; SOT94P280X100-5N; LCSC C841192
J6: USB-C; USB-C-16P-4LAYER-ISOLATED; LCSC C2765186
Q3: AO3401A; SOT23-R; LCSC C15127
R12: 100k; R0603
R20: 1M; R0603
R21: 240k; R0603
R36, R37: 5.1k; R0603

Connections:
3.3V: C10.1, C13.1, C14.1, IC3.3 (3V3), IC4.5 (VOUT); also elsewhere on the board
BATTERY: IC3.22 (IO18); also elsewhere on the board
CC3: J6.B5 (CC2), R36.2
CC4: J6.A5 (CC1), R37.2
D+: IC3.24 (IO20), J6.A6 (D+), J6.B6 (D+)
D-: IC3.23 (IO19), J6.A7 (D-), J6.B7 (D-)
EPD_BUSY: IC3.9 (IO5); also elsewhere on the board
EPD_CS: IC3.12 (IO8); also elsewhere on the board
EPD_DC: IC3.11 (IO7); also elsewhere on the board
EPD_DIN: IC3.31 (IO35); also elsewhere on the board
EPD_RST: IC3.10 (IO6); also elsewhere on the board
EPD_SCK: IC3.32 (IO36); also elsewhere on the board
GND: C8.2, C10.2, C13.2, C14.2, IC3.1 (GND_1), IC3.2 (GND_2), IC3.30 (GND_3), IC3.42 (GND_4), IC3.43 (GND_5), IC3.46 (GND_6), IC3.47 (GND_7), IC3.48 (GND_8), IC3.49 (GND_9), IC3.50 (GND_10), IC3.51 (GND_11), IC3.52 (GND_12), IC3.53 (GND_13), IC3.54 (GND_14), IC3.55 (GND_15), IC3.56 (GND_16), IC3.57 (GND_17), IC3.58 (GND_18), IC3.59 (GND_19), IC3.60 (GND_20), IC3.61 (GND_21), IC3.62 (GND_22), IC3.63 (GND_23), IC3.64 (GND_24), IC3.65 (GND_25), IC3.66 (GND_26), IC3.67 (GND_27), IC3.68 (GND_28), IC3.69 (GND_29), IC3.70 (GND_30), IC3.71 (GND_31), IC3.72 (GND_32), IC3.73 (GND_33), IC4.2 (GND), J6.GND, J6.GND2 (GND), R12.1, R21.1, R36.1, R37.1; also elsewhere on the board
IO0: IC3.4 (IO0); also elsewhere on the board
RST: IC3.45 (EN); also elsewhere on the board
RX: IC3.40 (RXD0); also elsewhere on the board
SCL: IC3.29 (IO34); also elsewhere on the board
SDA: IC3.28 (IO33); also elsewhere on the board
SENS: IC3.17 (IO13); also elsewhere on the board
TX: IC3.39 (TXD0); also elsewhere on the board
VBAT: C8.1, IC4.1 (VIN), IC4.3 (EN); also elsewhere on the board
VBUS: D10.A, J6.VBUS1 (VBUS), J6.VBUS2 (VBUS), Q3.1 (G), R12.2
VIN: D10.C, Q3.2 (S); also elsewhere on the board
VSOL: Q3.3 (D), R20.1
VSOLAR: IC3.21 (IO17), R20.2, R21.2

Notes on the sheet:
Microcontroller
Input power/data connectors
Power reg

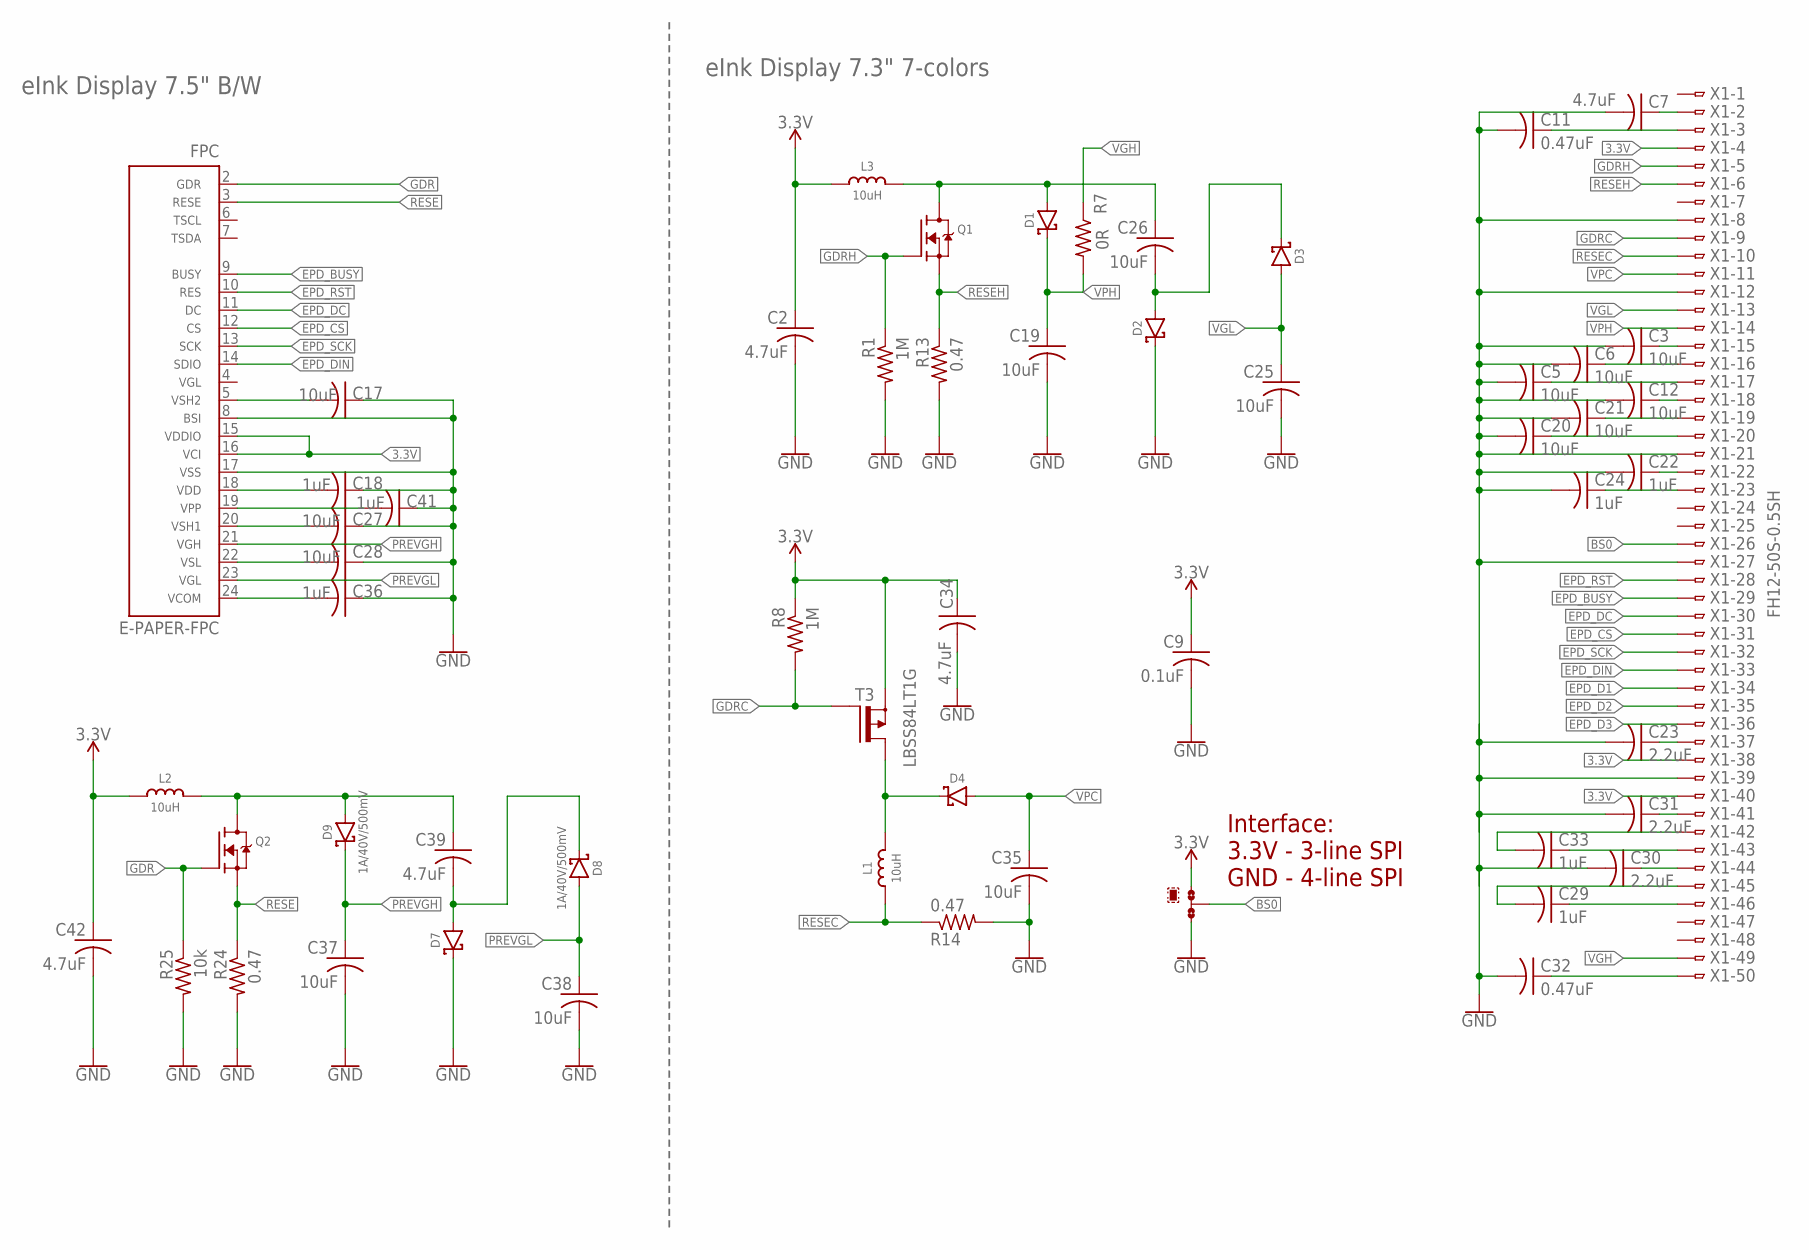
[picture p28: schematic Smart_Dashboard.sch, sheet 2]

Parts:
C2, C7, C34, C39, C42: 4.7uF; C0603
C3, C5, C6, C12, C17, C19, C20, C21, C25, C26, C27, C28, C35, C37, C38: 10uF; C0603
C9: 0.1uF; C0603
C11, C32: 0.47uF; C0603
C18, C22, C24, C29, C33, C36, C41: 1uF; C0603
C23, C30, C31: 2.2uF; C0603
D1, D2, D3, D4, D7, D8, D9: 1A/40V/500mV; SMA-DIODE
FPC: E-PAPER-FPC; FPC-05FB-24PH20
JMP1: 0R-JUMPA; A0R-JMP
L1, L2, L3: 10uH; INDUCTOR_4X4MM_NR401
Q1, Q2: IRLML0100; SOT23-3
R1, R8: 1M; R0603
R7: 0R; R0603
R13, R14, R24: 0.47; R0603
R25: 10k; R0603
T3: LBSS84LT1G; SOT23
X1: FH12-50S-0.5SH

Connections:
3.3V: C2.1, C9.1, C34.1, C42.1, FPC.15, FPC.16, JMP1.1, L2.P$2 (2), L3.P$2 (2), R8.1, T3.2 (S), X1.4, X1.38, X1.40; also elsewhere on the board
BS0: JMP1.2, X1.26
EPD_BUSY: FPC.9, X1.29; also elsewhere on the board
EPD_CS: FPC.12, X1.31; also elsewhere on the board
EPD_D1: X1.34
EPD_D2: X1.35
EPD_D3: X1.36
EPD_DC: FPC.11, X1.30; also elsewhere on the board
EPD_DIN: FPC.14, X1.33; also elsewhere on the board
EPD_RST: FPC.10, X1.28; also elsewhere on the board
EPD_SCK: FPC.13, X1.32; also elsewhere on the board
GDR: FPC.2, Q2.1 (G), R25.1
GDRC: R8.2, T3.1 (G), X1.9
GDRH: Q1.1 (G), R1.1, X1.5
GND: C2.2, C3.2, C5.2, C6.2, C7.2, C9.2, C11.2, C12.2, C17.1, C18.1, C19.2, C20.2, C21.2, C22.2, C23.2, C24.2, C25.2, C27.1, C28.1, C30.2, C31.2, C32.2, C34.2, C35.2, C36.1, C37.2, C38.2, C41.1, C42.2, D2.C, D7.C, FPC.8, FPC.17, JMP1.3, R1.2, R13.2, R14.2, R24.2, R25.2, X1.8, X1.12, X1.21, X1.27, X1.39; also elsewhere on the board
unnamed: C7.1, X1.2
unnamed: C3.1, X1.15
unnamed: C5.1, X1.17
unnamed: C17.2, FPC.5
unnamed: C18.2, FPC.18
unnamed: C27.2, FPC.20
unnamed: C26.2, D2.A, D3.C
unnamed: C26.1, D1.A, L3.P$1 (1), Q1.3 (D)
unnamed: C28.2, FPC.22
unnamed: C36.2, FPC.24
unnamed: C6.1, X1.16
unnamed: C11.1, X1.3
unnamed: C12.1, X1.18
unnamed: C20.1, X1.20
unnamed: C21.1, X1.19
unnamed: C22.1, X1.22
unnamed: C23.1, X1.37
unnamed: C24.1, X1.23
unnamed: C29.1, X1.46
unnamed: C29.2, X1.45
unnamed: C30.1, X1.44
unnamed: C31.1, X1.41
unnamed: C32.1, X1.50
unnamed: C33.1, X1.43
unnamed: C33.2, X1.42
unnamed: C39.2, D7.A, D8.C
unnamed: D4.C, L1.P$1 (1), T3.3 (D)
unnamed: C39.1, D9.A, L2.P$1 (1), Q2.3 (D)
unnamed: C41.2, FPC.19
PREVGH: C37.1, D9.C, FPC.21
PREVGL: C38.1, D8.A, FPC.23
RESE: FPC.3, Q2.2 (S), R24.1
RESEC: L1.P$2 (2), R14.1, X1.10
RESEH: Q1.2 (S), R13.1, X1.6
VGH: R7.1, X1.49
VGL: C25.1, D3.A, X1.13
VPC: C35.1, D4.A, X1.11
VPH: C19.1, D1.C, R7.2, X1.14

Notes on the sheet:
eInk Display 7.5" B/W
eInk Display 7.3" 7-colors
Interface: 3.3V - 3-line SPI GND - 4-line SPI

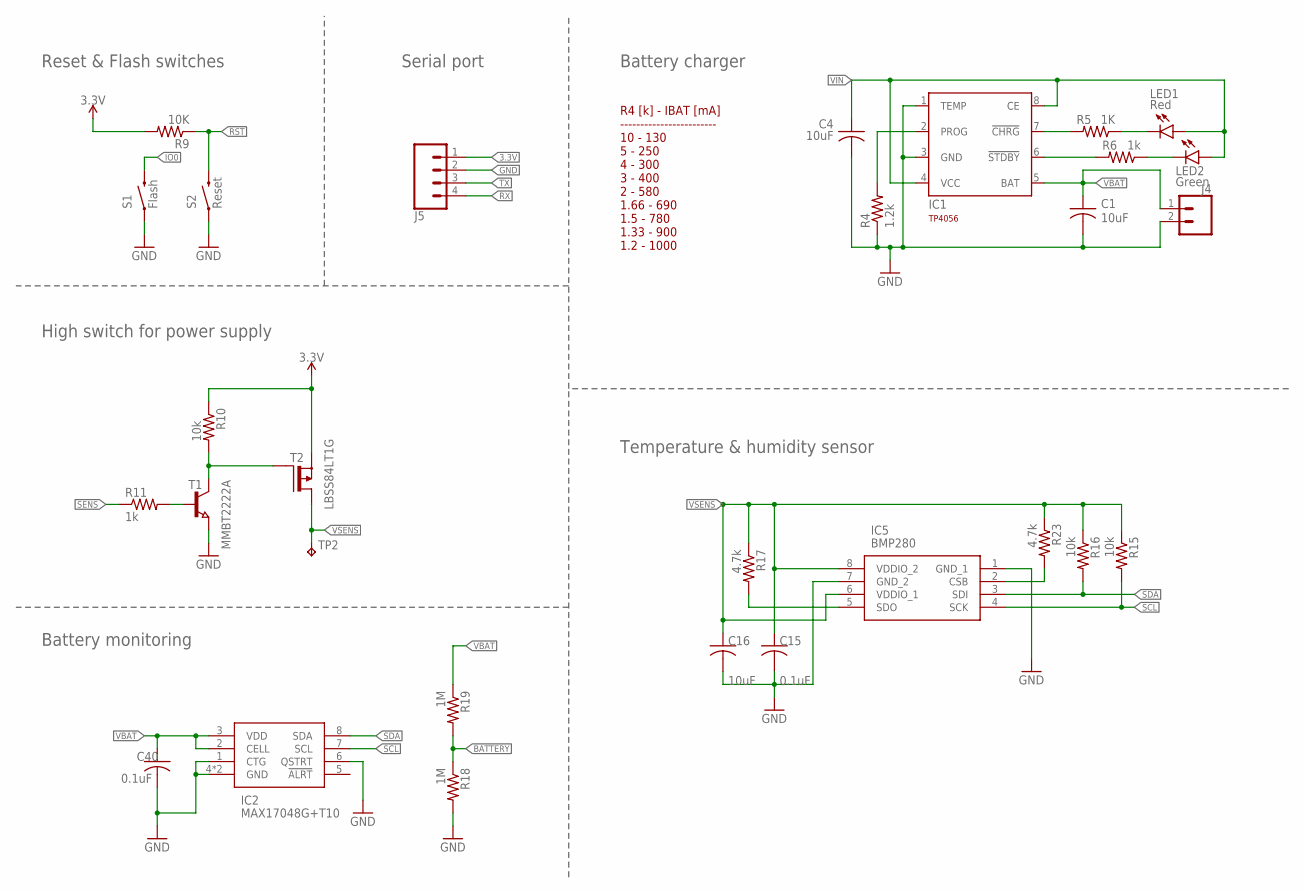
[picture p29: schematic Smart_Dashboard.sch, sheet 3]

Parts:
C1, C4, C16: 10uF; C0603
C15, C40: 0.1uF; C0603
IC1: TP4056; SOT23-8; LCSC C16581
IC2: MAX17048G+T10; SON50P200X200X80-9N
IC5: BMP280; 8-PIN-METAL-LID-LGA
J4: CONN_02-JST-2MM-SMT; JST-2-SMD; LCSC C3029440
J5: CONN_04PTH; 1X04
LED1: Red; LED_0603
LED2: Green; LED_0603
R4: 1.2k; R0603
R5: 1K; R0603
R6, R11: 1k; R0603
R9: 10K; R0603
R10, R15, R16: 10k; R0603
R17, R23: 4.7k; R0603
R18, R19: 1M; R0603
S1: Flash; TACTILE_SWITCH_SMD_5.2MM
S2: Reset; TACTILE_SWITCH_SMD_5.2MM
T1: MMBT2222A; SOT23
T2: LBSS84LT1G; SOT23
TP2: TPB1,27; B1,27

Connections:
3.3V: J5.1, R9.2, R10.1, T2.2 (S); also elsewhere on the board
BATTERY: R18.1, R19.2; also elsewhere on the board
GND: C1.2, C4.2, C15.2, C16.2, C40.2, IC1.1 (TEMP), IC1.3 (GND), IC2.1 (CTG), IC2.4 (GND), IC2.6 (QSTRT), IC2.9 (GND), IC5.1 (GND_1), IC5.7 (GND_2), J4.2 (1), J5.2, R4.1, R18.2, S1.1, S2.1, T1.2 (E); also elsewhere on the board
IO0: S1.3 (2); also elsewhere on the board
unnamed: IC1.6 (!STDBY), R6.2
unnamed: LED1.C, R5.1
unnamed: LED2.C, R6.1
unnamed: IC1.2 (PROG), R4.2
unnamed: IC1.7 (!CHRG), R5.2
unnamed: R10.2, T1.3 (C), T2.1 (G)
unnamed: IC5.5 (SDO), R17.2
unnamed: IC5.2 (CSB), R23.2
unnamed: R11.2, T1.1 (B)
RST: R9.1, S2.3 (2); also elsewhere on the board
RX: J5.4; also elsewhere on the board
SCL: IC2.7 (SCL), IC5.4 (SCK), R15.2; also elsewhere on the board
SDA: IC2.8 (SDA), IC5.3 (SDI), R16.2; also elsewhere on the board
SENS: R11.1; also elsewhere on the board
TX: J5.3; also elsewhere on the board
VBAT: C1.1, C40.1, IC1.5 (BAT), IC2.2 (CELL), IC2.3 (VDD), J4.1 (2), R19.1; also elsewhere on the board
VIN: C4.1, IC1.4 (VCC), IC1.8 (CE), LED1.A, LED2.A; also elsewhere on the board
VSENS: C15.1, C16.1, IC5.6 (VDDIO_1), IC5.8 (VDDIO_2), R15.1, R16.1, R17.1, R23.1, T2.3 (D), TP2.TP

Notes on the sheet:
High switch for power supply
Temperature & humidity sensor
Battery monitoring
R4 [k] - IBAT [mA] ------------------------ 10 - 130 5 - 250 4 - 300 3 - 400 2 - 580 1.66 - 690 1.5 - 780 1.33 - 900 1.2 - 1000
Battery charger
Reset & Flash switches
Serial port

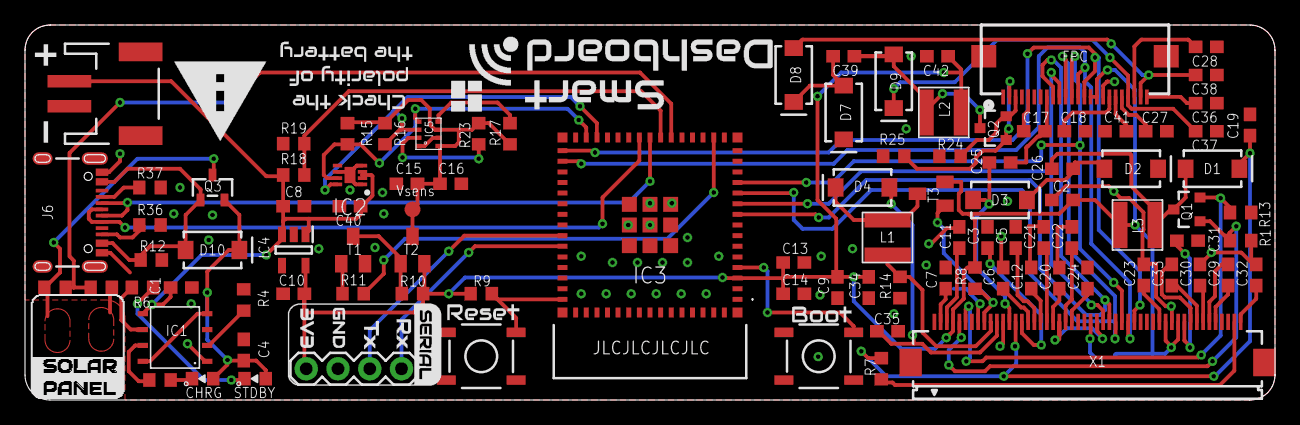
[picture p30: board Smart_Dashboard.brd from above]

Board: 2 copper layers, 100.0 x 30.0 mm, 99 parts (1 on the bottom side), 77 nets.

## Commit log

2023-11-14 Added design files
    [Smart_Dashboard.brd, Smart_Dashboard.sch]
2023-11-14 Added enclosure files
    [Bottom.stl, Top.stl]

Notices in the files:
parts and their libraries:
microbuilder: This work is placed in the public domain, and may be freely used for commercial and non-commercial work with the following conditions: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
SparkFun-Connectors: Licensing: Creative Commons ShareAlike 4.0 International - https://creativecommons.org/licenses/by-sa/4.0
